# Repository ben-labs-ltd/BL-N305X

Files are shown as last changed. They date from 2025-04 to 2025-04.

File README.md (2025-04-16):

# BL-N305X
Meshtastic intended LoRa Node - Ben Labs Node 30.5dBm

## BL-N305A

Prototype board

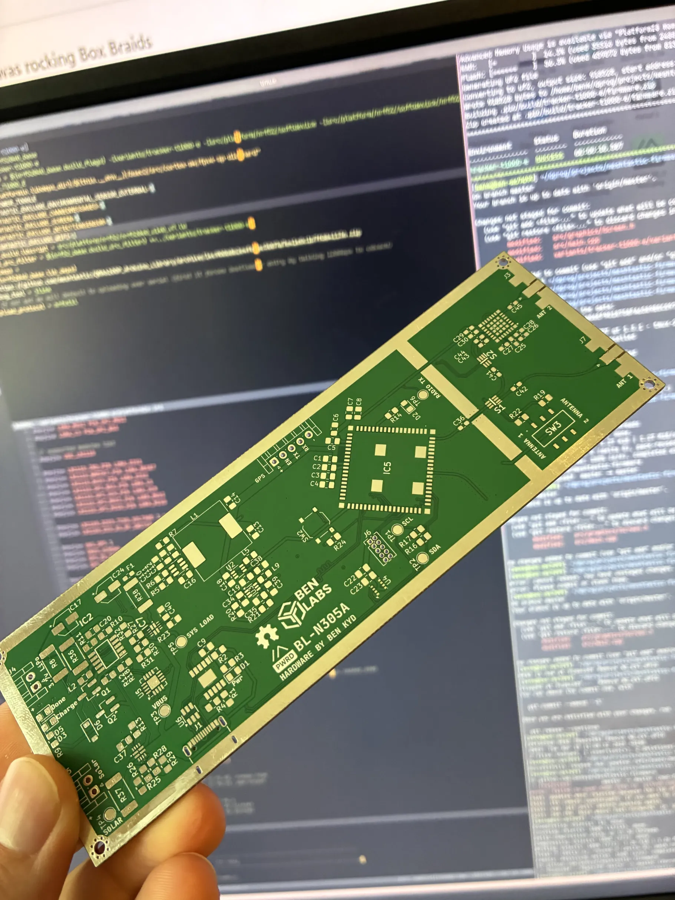
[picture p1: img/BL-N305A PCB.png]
Unpopulated PCB


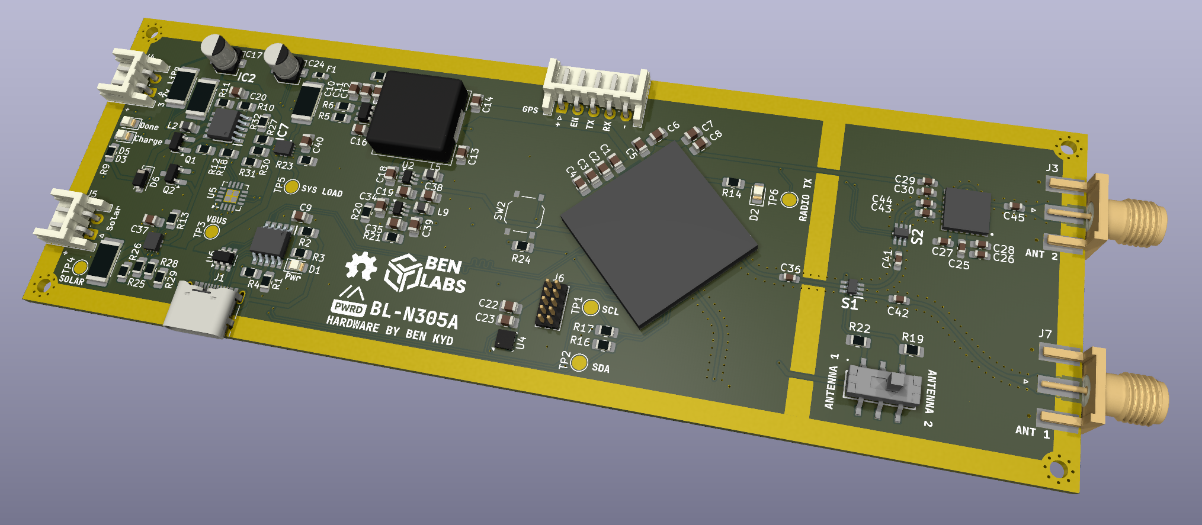
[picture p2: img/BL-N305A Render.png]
Render


## BL-N305B

Production ready board

OEM Price Point target £50
DIY Price Point target £30

### Considerations
- Use the SKY66122
- Move to using a bias-tee module for the amplification
- Compact compact compact

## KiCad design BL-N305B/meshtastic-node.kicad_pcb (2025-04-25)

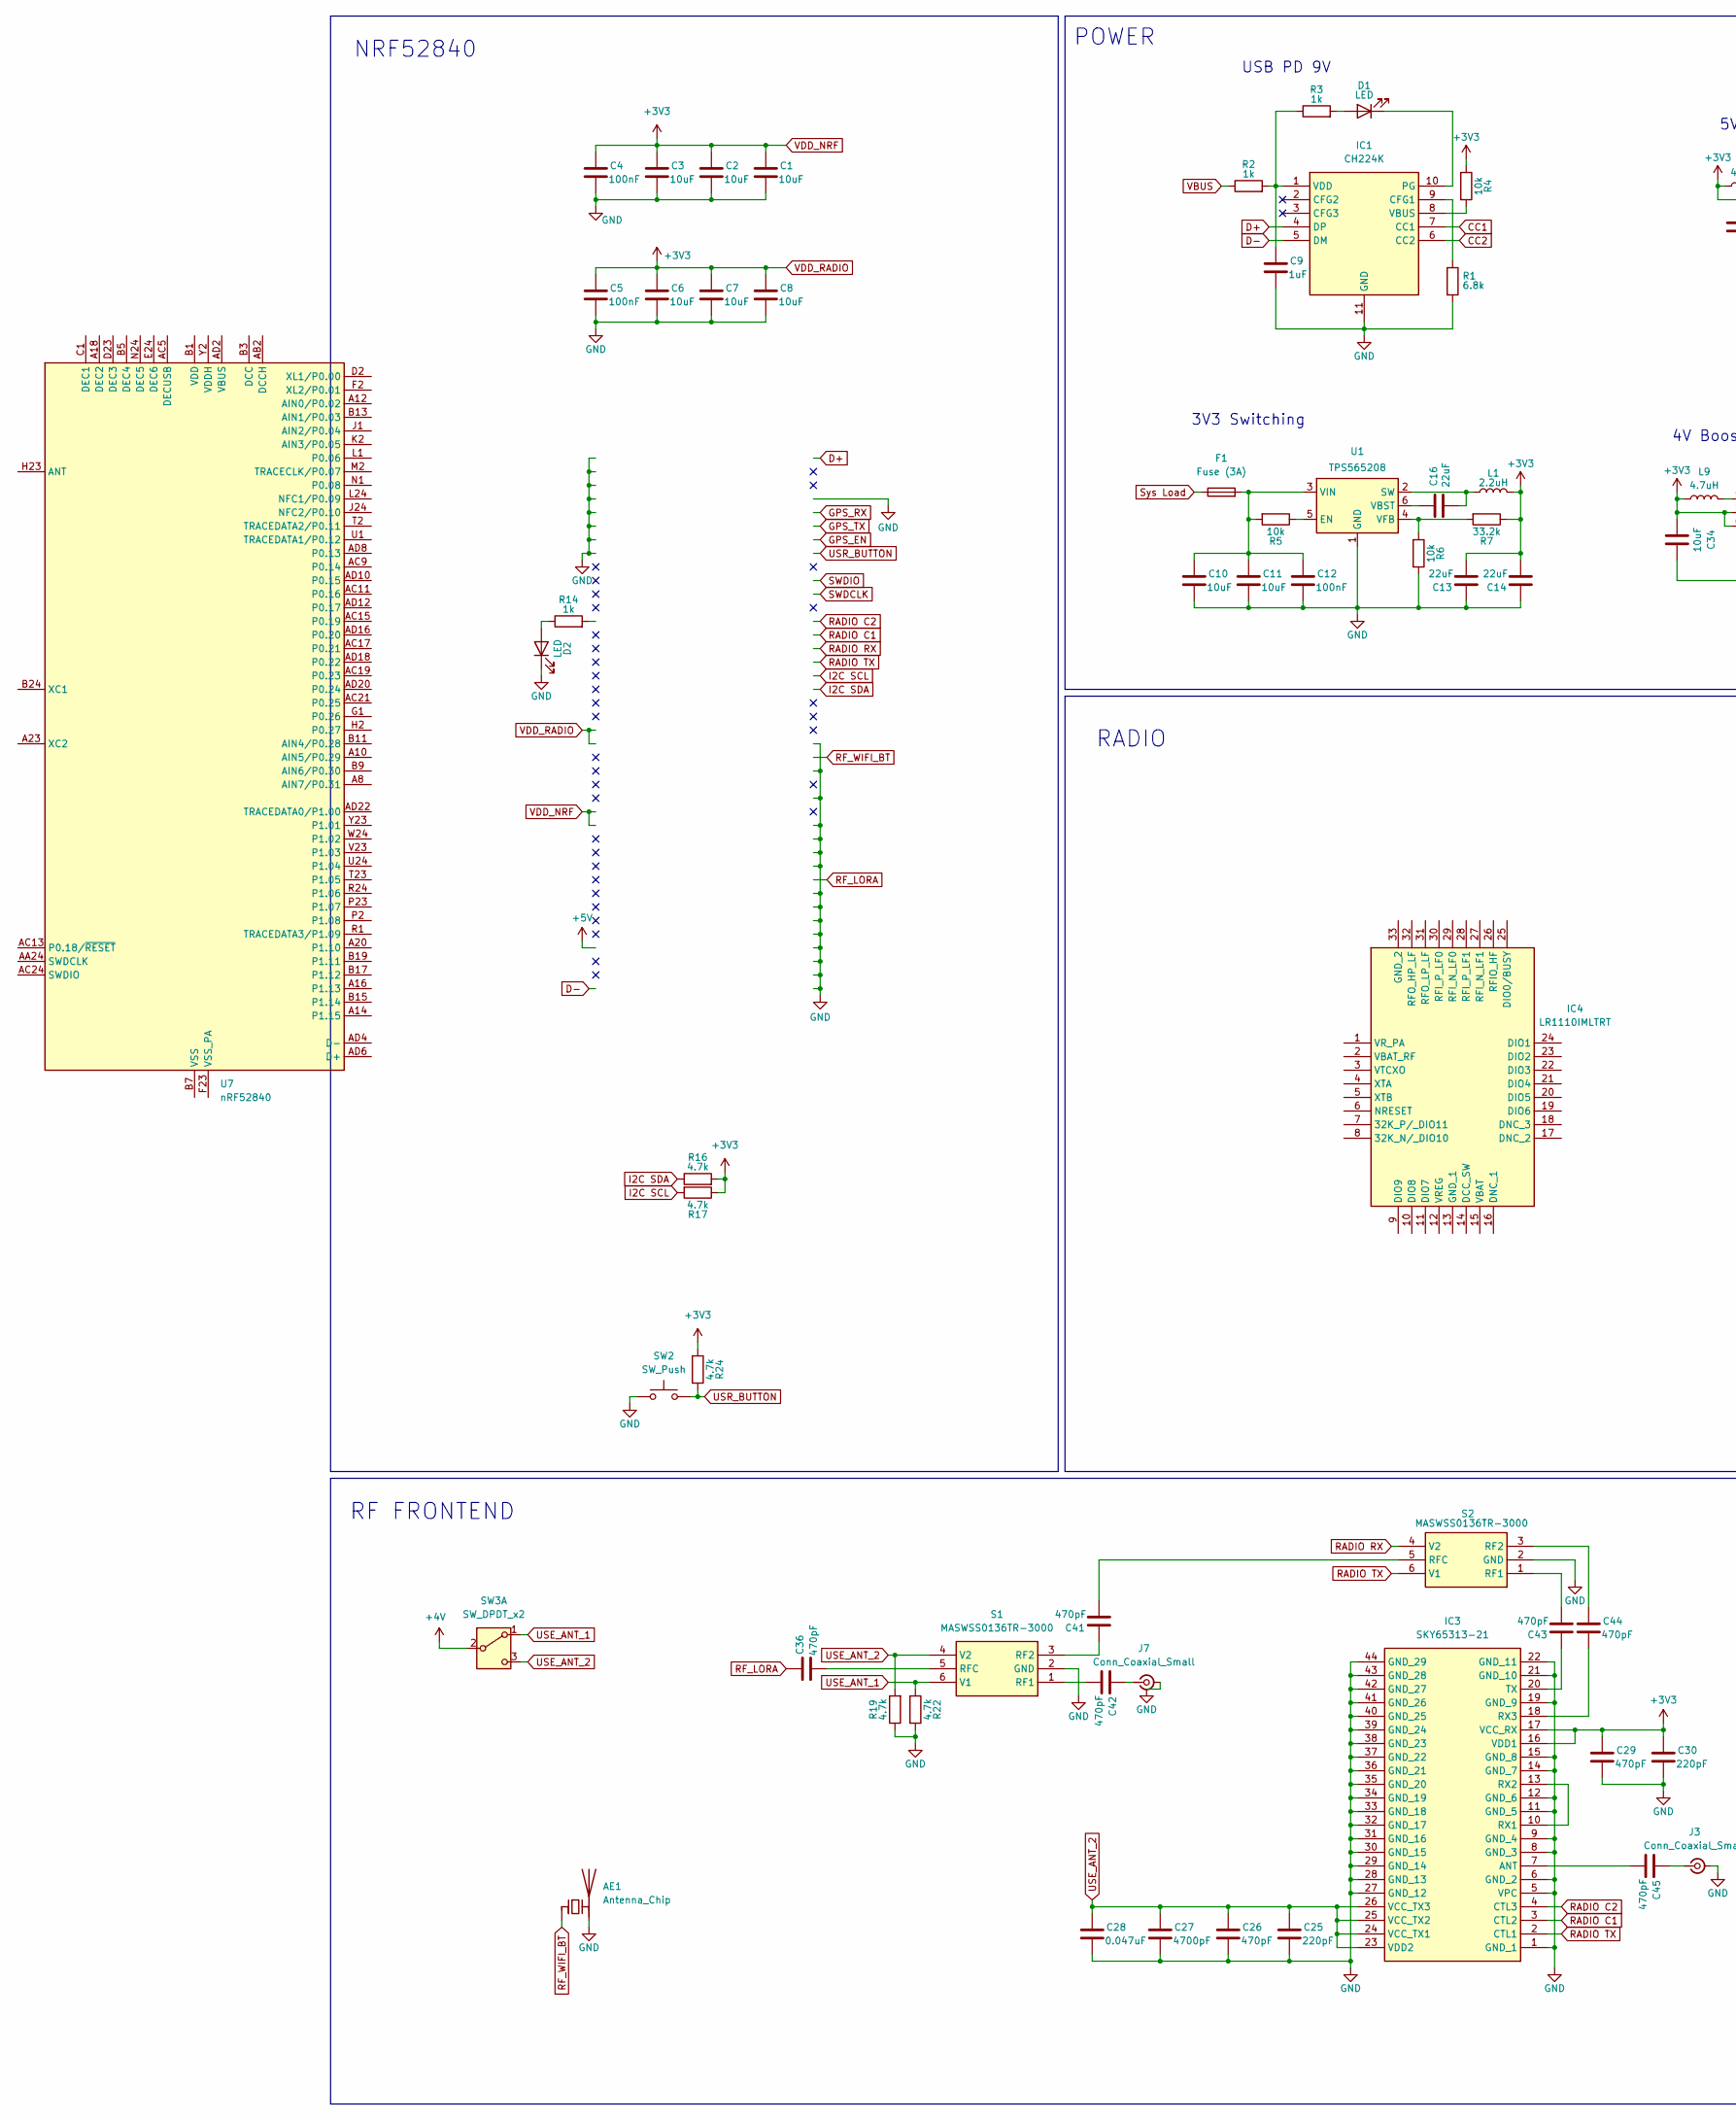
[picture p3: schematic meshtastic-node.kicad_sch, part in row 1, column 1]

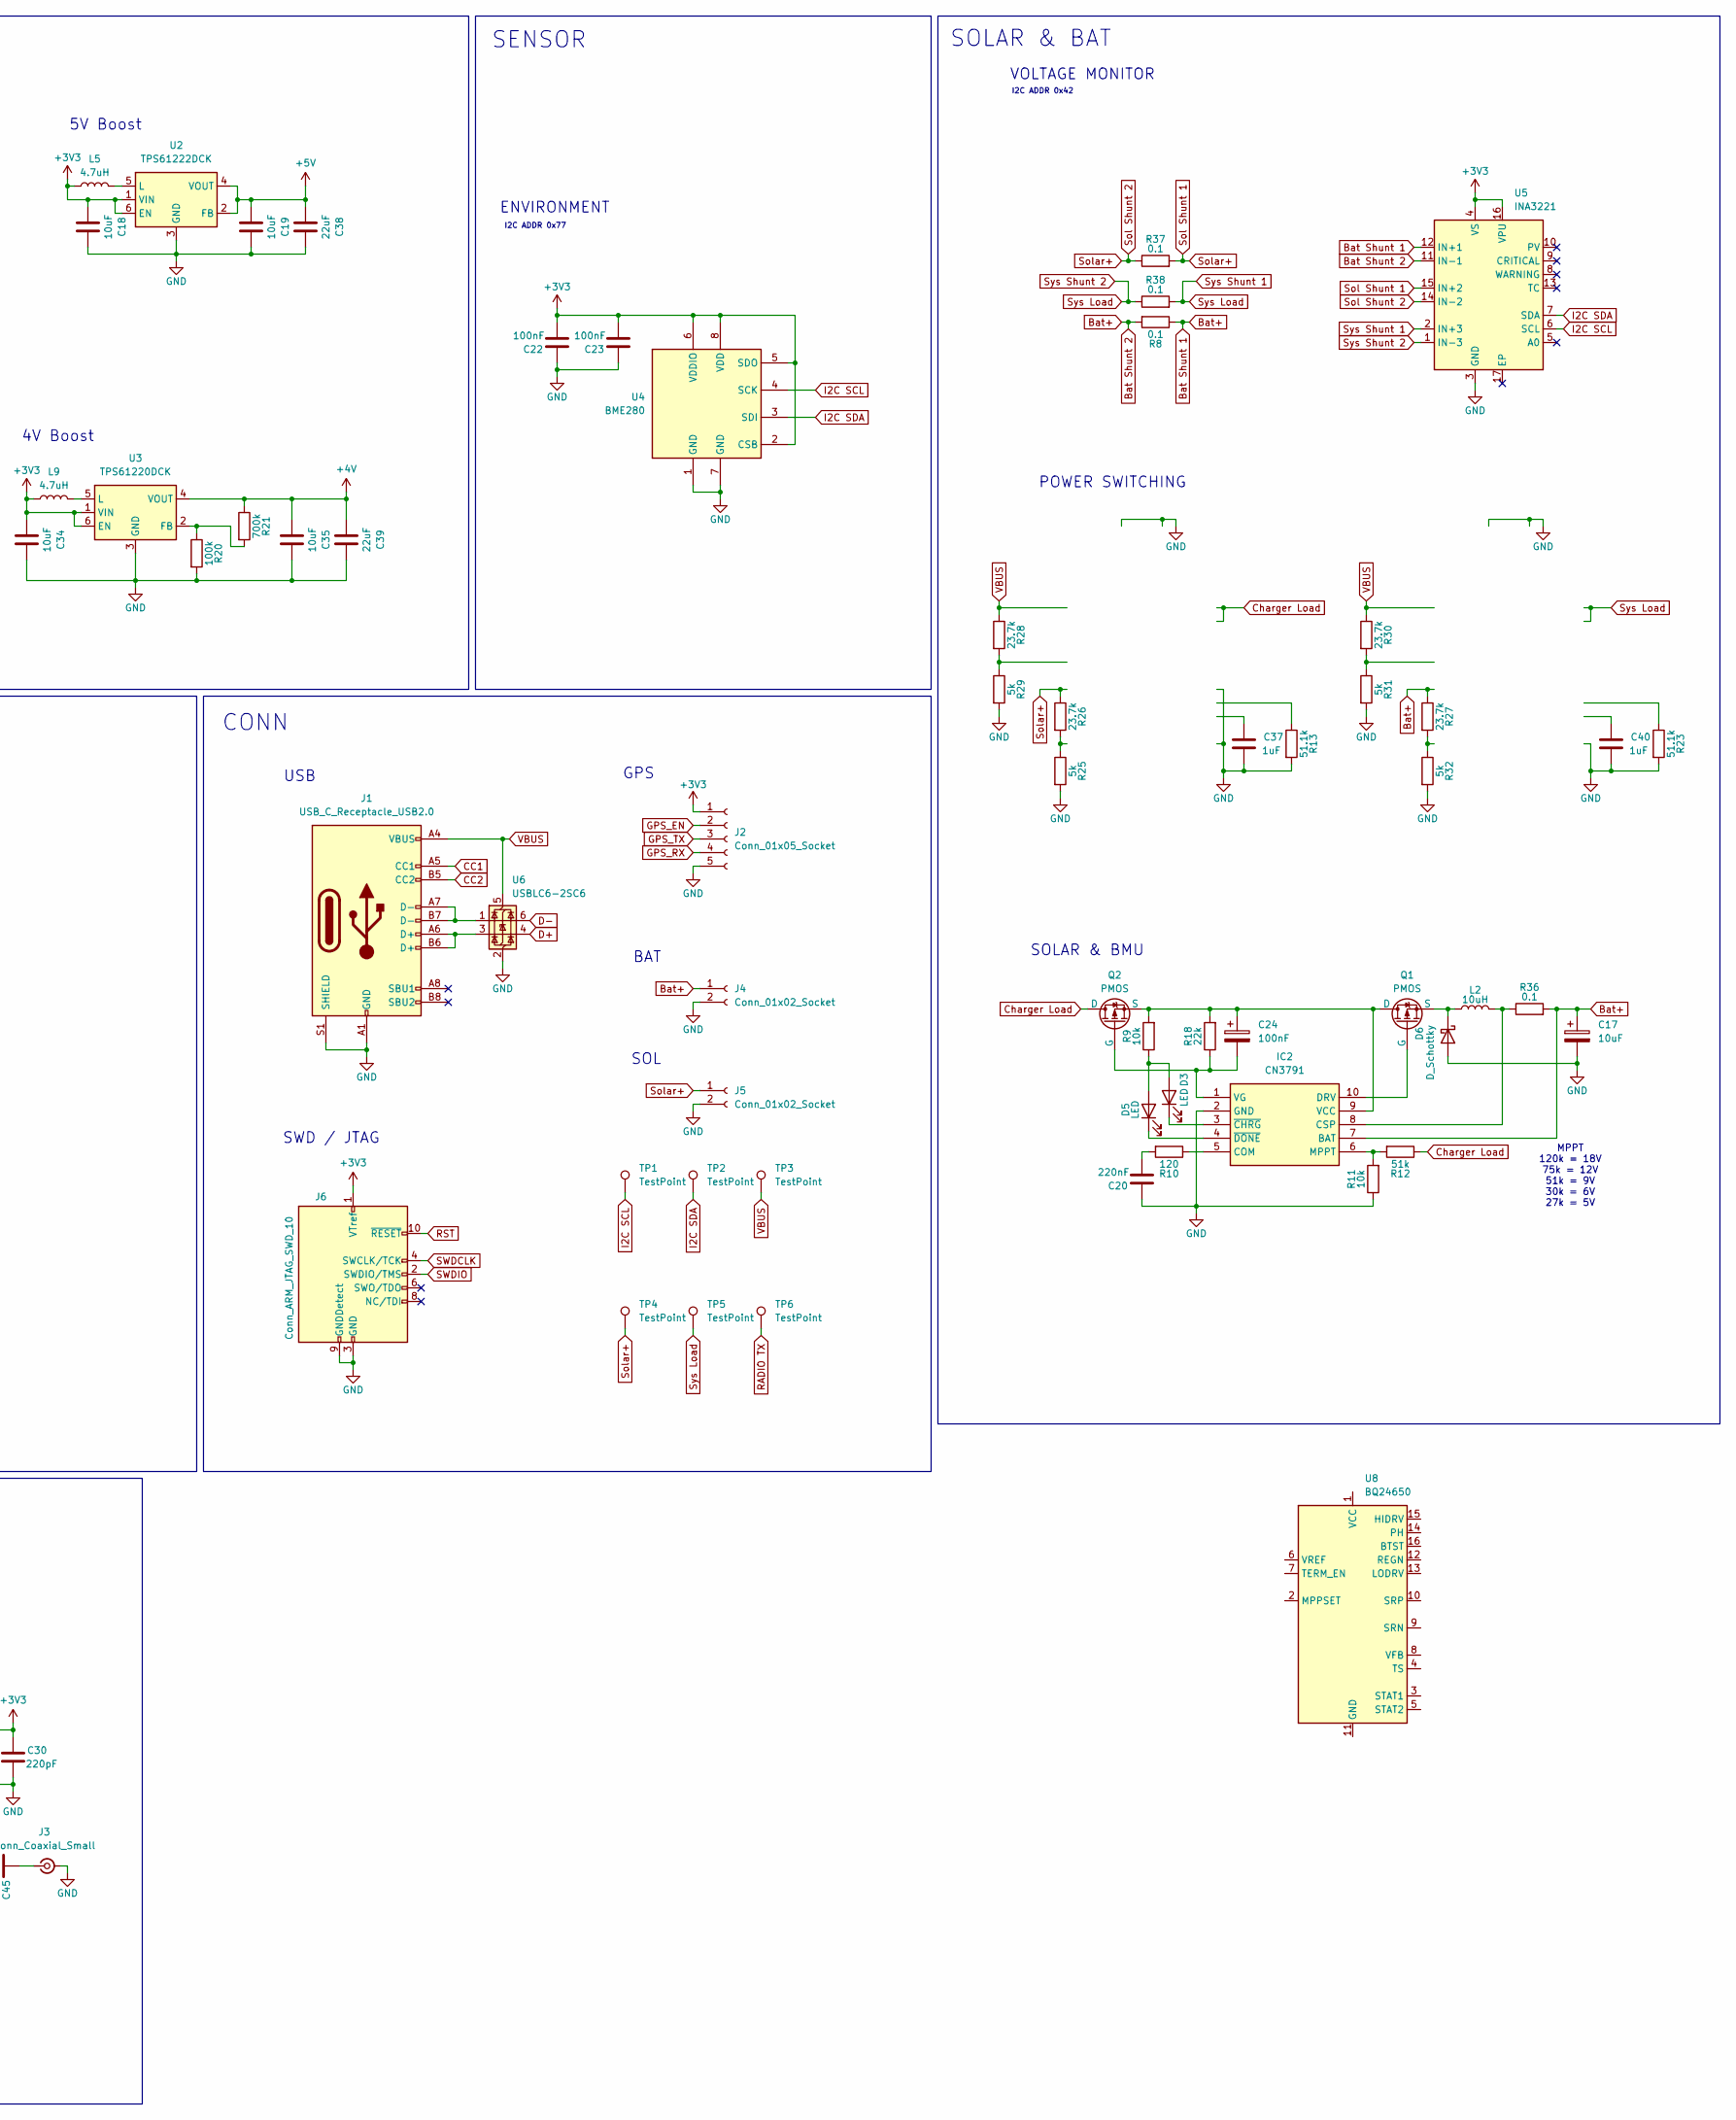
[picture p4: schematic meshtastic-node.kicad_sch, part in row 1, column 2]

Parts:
AE1: Antenna_Chip; Texas_SWRA117D_2.4GHz_Left
C1, C2, C3, C6, C7, C8, C10, C11, C18, C19, C34, C35: 10uF; C_0805_2012Metric_Pad1.18x1.45mm_HandSolder
C4, C5, C12, C22, C23: 100nF; C_0805_2012Metric_Pad1.18x1.45mm_HandSolder
C9, C37, C40: 1uF; C_0805_2012Metric_Pad1.18x1.45mm_HandSolder
C13, C14, C16, C38, C39: 22uF; C_0805_2012Metric_Pad1.18x1.45mm_HandSolder
C17: 10uF; CP_Elec_4x5.4
C20: 220nF; C_0805_2012Metric_Pad1.18x1.45mm_HandSolder
C24: 100nF; CP_Elec_4x5.4
C25, C30: 220pF; C_0603_1608Metric_Pad1.08x0.95mm_HandSolder
C26, C29, C36, C41, C42, C43, C44, C45: 470pF; C_0603_1608Metric_Pad1.08x0.95mm_HandSolder
C27: 4700pF; C_0603_1608Metric_Pad1.08x0.95mm_HandSolder
C28: 0.047uF; C_0603_1608Metric_Pad1.08x0.95mm_HandSolder
D1, D2, D3, D5: LED; LED_0805_2012Metric_Pad1.15x1.40mm_HandSolder
D6: D_Schottky; D_SOD-123
F1: Fuse (3A); Fuse_0603_1608Metric_Pad1.05x0.95mm_HandSolder
IC1: CH224K; SOP100P600X180-11N; Manufacturer_Part_Number CH224K; LCSC C970725
IC2: CN3791; SOP100P600X175-10N; Manufacturer_Part_Number CN3791; LCSC C154992
IC3: SKY65313-21; SKY6531321; Manufacturer_Part_Number SKY65313-21; Mouser Part Number 873-SKY65313-21
IC4: LR1110IMLTRT; QFN50P500X500X100-33N-D; Manufacturer_Part_Number LR1110IMLTRT; Mouser Part Number 947-LR1110IMLTRT
J1: USB_C_Receptacle_USB2.0; USB_C_Receptacle_G-Switch_GT-USB-7010ASV
J2: Conn_01x05_Socket; JST_EH_S5B-EH_1x05_P2.50mm_Horizontal
J3, J7: Conn_Coaxial_Small; SMA_Molex_73251-1153_EdgeMount_Horizontal
J4, J5: Conn_01x02_Socket; JST_EH_S2B-EH_1x02_P2.50mm_Horizontal
J6: Conn_ARM_JTAG_SWD_10; PinHeader_2x05_P1.27mm_Vertical
L1: 2.2uH; L_SXN_SMDRI124; LCSC C2929497
L2: 10uH; L_0805_2012Metric_Pad1.15x1.40mm_HandSolder
L5, L9: 4.7uH; L_0805_2012Metric_Pad1.15x1.40mm_HandSolder
Q1, Q2: PMOS; SOT-23_Handsoldering
R1: 6.8k; R_0805_2012Metric_Pad1.20x1.40mm_HandSolder
R2, R3, R14: 1k; R_0805_2012Metric_Pad1.20x1.40mm_HandSolder
R4, R5, R6, R9, R11: 10k; R_0805_2012Metric_Pad1.20x1.40mm_HandSolder
R7: 33.2k; R_0805_2012Metric_Pad1.20x1.40mm_HandSolder
R8, R36, R37, R38: 0.1; R_2512_6332Metric_Pad1.40x3.35mm_HandSolder
R10: 120; R_0805_2012Metric_Pad1.20x1.40mm_HandSolder
R12: 51k; R_0805_2012Metric_Pad1.20x1.40mm_HandSolder
R13, R23: 51.1k; R_0805_2012Metric_Pad1.20x1.40mm_HandSolder
R16, R17, R19, R22, R24: 4.7k; R_0805_2012Metric_Pad1.20x1.40mm_HandSolder
R18: 22k; R_0805_2012Metric_Pad1.20x1.40mm_HandSolder
R20: 100k; R_0805_2012Metric_Pad1.20x1.40mm_HandSolder
R21: 700k; R_0805_2012Metric_Pad1.20x1.40mm_HandSolder
R25, R29, R31, R32: 5k; R_0805_2012Metric_Pad1.20x1.40mm_HandSolder
R26, R27, R28, R30: 23.7k; R_0805_2012Metric_Pad1.20x1.40mm_HandSolder
S1, S2: MASWSS0136TR-3000; SOT65P210X110-6N; Manufacturer_Part_Number MASWSS0136TR-3000; Mouser Part Number 937-MASWSS0136-T
SW2: SW_Push; SW_Push_1P1T_XKB_TS-1187A; LCSC C42420254
SW3: SW_DPDT_x2; SS3235SL3; LCSC C381098
TP1, TP2, TP3, TP4, TP5, TP6: TestPoint; TestPoint_Pad_D2.0mm
U1: TPS565208; SOT-23-6; LCSC C2650336
U2: TPS61222DCK; Texas_R-PDSO-G6; LCSC C116461
U3: TPS61220DCK; Texas_R-PDSO-G6; LCSC C116461
U4: BME280; Bosch_LGA-8_2.5x2.5mm_P0.65mm_ClockwisePinNumbering; LCSC C92489
U5: INA3221; Texas_RGV0016A_VQFN-16-1EP_4x4mm_P0.65mm_EP2.1x2.1mm; LCSC C181255
U6: USBLC6-2SC6; SOT-23-6
U7: nRF52840; Nordic_AQFN-73-1EP_7x7mm_P0.5mm
U8: BQ24650; Texas_RVA_VQFN-16-1EP_3.5x3.5mm_P0.5mm_EP2.14x2.14mm_Therma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

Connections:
+4V: C35.1, C39.1, R21.1, SW3.2 (B), U3.4 (VOUT)
+5V: C19.1, C38.1, U2.2 (FB), U2.4 (VOUT)
Bat Shunt 1: C17.1, IC2.7 (BAT), J4.1, R8.1, R8.2, R27.1, R36.2, U5.11 (IN-1), U5.12 (IN+1)
CC1: IC1.7 (CC1), J1.A5 (CC1)
CC2: IC1.6 (CC2), J1.B5 (CC2)
Charger Load: Q2.1 (D), R12.1
D+: IC1.4 (DP), U6.4 (I/O2)
D-: IC1.5 (DM), U6.6 (I/O1)
GND: AE1.2 (PCB_Trace), C1.2, C2.2, C3.2, C4.2, C5.2, C6.2, C7.2, C8.2, C9.2, C10.2, C11.2, C12.2, C13.1, C14.1, C17.2, C18.2, C19.2, C20.1, C22.1, C23.1, C25.2, C26.2, C27.2, C28.2, C29.2, C30.2, C34.2, C35.2, C37.2, C38.2, C39.2, C40.2, D2.1 (K), D6.2 (A), IC1.11 (GND), IC2.2 (GND), IC3.1 (GND_1), IC3.5 (VPC), IC3.6 (GND_2), IC3.8 (GND_3), IC3.9 (GND_4), IC3.11 (GND_5), IC3.12 (GND_6), IC3.14 (GND_7), IC3.15 (GND_8), IC3.19 (GND_9), IC3.21 (GND_10), IC3.22 (GND_11), IC3.27 (GND_12), IC3.28 (GND_13), IC3.29 (GND_14), IC3.30 (GND_15), IC3.31 (GND_16), IC3.32 (GND_17), IC3.33 (GND_18), IC3.34 (GND_19), IC3.35 (GND_20), IC3.36 (GND_21), IC3.37 (GND_22), IC3.38 (GND_23), IC3.39 (GND_24), IC3.40 (GND_25), IC3.41 (GND_26), IC3.42 (GND_27), IC3.43 (GND_28), IC3.44 (GND_29), J1.A1 (GND), J1.A12 (GND), J1.B1 (GND), J1.B12 (GND), J1.S1 (SHIELD), J2.5, J3.2 (Ext), J4.2, J5.2, J6.3 (GND), J6.5 (GND), J6.9 (GNDDetect), J7.2 (Ext), R1.2, R6.2, R11.1, R13.2, R19.1, R20.2, R22.2, R23.2, R25.2, R29.2, R31.2, R32.2, S1.2 (GND), S2.2 (GND), SW2.1, U1.1 (GND), U2.3 (GND), U3.3 (GND), U4.1 (GND), U4.7 (GND), U5.3 (GND), U6.2 (GND)
GPS_EN: J2.2
GPS_RX: J2.4
GPS_TX: J2.3
I2C SCL: R17.2, TP1.1, U4.4 (SCK), U5.6 (SCL)
I2C SDA: R16.1, TP2.1, U4.3 (SDI), U5.7 (SDA)
unnamed: C20.2, R10.2
unnamed: D1.2 (A), R3.2
unnamed: D1.1 (K), IC1.10 (PG)
unnamed: D2.2 (A), R14.1
unnamed: D3.2 (A), D5.2 (A), R9.1
unnamed: D3.1 (K), IC2.3 (~CHRG)
unnamed: D5.1 (K), IC2.4 (~DONE)
unnamed: D6.1 (K), L2.1, Q1.3 (S)
unnamed: IC1.9 (CFG1), R1.1
unnamed: IC1.8 (VBUS), R4.2
unnamed: C9.1, IC1.1 (VDD), R2.2, R3.1
unnamed: IC2.5 (COM), R10.1
unnamed: IC2.8 (CSP), L2.2, R36.1
unnamed: IC2.10 (DRV), Q1.2 (G)
unnamed: IC2.6 (MPPT), R11.2, R12.2
unnamed: C24.1, IC2.9 (VCC), Q1.1 (D), Q2.3 (S), R9.2, R18.2
unnamed: C24.2, IC2.1 (VG), Q2.2 (G), R18.1
unnamed: C45.2, IC3.7 (ANT)
unnamed: IC3.10 (RX1), IC3.13 (RX2)
unnamed: C44.2, IC3.18 (RX3)
unnamed: C43.1, IC3.20 (TX)
unnamed: J1.A6 (D+), J1.B6 (D+), U6.3 (I/O2)
unnamed: J1.A7 (D-), J1.B7 (D-), U6.1 (I/O1)
unnamed: C45.1, J3.1 (In)
unnamed: C42.1, J7.1 (In)
unnamed: R25.1, R26.2
unnamed: R27.2, R32.1
unnamed: R28.2, R29.1
unnamed: R30.2, R31.1
unnamed: C42.2, S1.1 (RF1)
unnamed: C41.1, S1.3 (RF2)
unnamed: C36.2, S1.5 (RFC)
unnamed: C43.2, S2.1 (RF1)
unnamed: C44.1, S2.3 (RF2)
unnamed: C41.2, S2.5 (RFC)
unnamed: R5.1, U1.5 (EN)
unnamed: C16.2, L1.1, U1.2 (SW)
unnamed: C16.1, U1.6 (VBST)
unnamed: R6.1, R7.2, U1.4 (VFB)
unnamed: C10.1, C11.1, C12.1, F1.2, R5.2, U1.3 (VIN)
unnamed: L5.2, U2.5 (L)
unnamed: R20.1, R21.2, U3.2 (FB)
unnamed: L9.2, U3.5 (L)
unnamed: U7.A22 (VDD), U7.AD14 (VDD), U7.AD23 (VDD), U7.B1 (VDD), U7.W1 (VDD)
unnamed: U7.B7 (VSS), U7.EP (VSS)
unnamed: U8.11 (GND), U8.17 (GND)
RADIO C1: IC3.3 (CTL2)
RADIO C2: IC3.4 (CTL3)
RADIO RX: S2.4 (V2)
RADIO TX: IC3.2 (CTL1), S2.6 (V1), TP6.1
RF_LORA: C36.1
RF_WIFI_BT: AE1.1 (FEED)
RST: J6.10 (~RESET)
SWDCLK: J6.4 (SWCLK/TCK)
SWDIO: J6.2 (SWDIO/TMS)
Sol Shunt 1: J5.1, R26.1, R37.1, R37.2, TP4.1, U5.14 (IN-2), U5.15 (IN+2)
Sys Load: F1.1, R38.1, R38.2, TP5.1, U5.1 (IN-3), U5.2 (IN+3)
USE_ANT_1: R22.1, S1.6 (V1), SW3.1 (A)
USE_ANT_2: C25.1, C26.1, C27.1, C28.1, IC3.23 (VDD2), IC3.24 (VCC_TX1), IC3.25 (VCC_TX2), IC3.26 (VCC_TX3), R19.2, S1.4 (V2), SW3.3 (C)
USR_BUTTON: R24.2, SW2.2
VBUS: J1.A4 (VBUS), J1.A9 (VBUS), J1.B4 (VBUS), J1.B9 (VBUS), R2.1, R28.1, R30.1, TP3.1, U6.5 (VBUS)
VDD_NRF: C1.1, C2.1, C3.1, C4.1, C5.1, C6.1, C7.1, C8.1, C13.2, C14.2, C18.1, C22.2, C23.2, C29.1, C30.1, C34.1, IC3.16 (VDD1), IC3.17 (VCC_RX), J2.1, J6.1 (VTref), L1.2, L5.1, L9.1, R4.1, R7.1, R16.2, R17.1, R24.1, U2.1 (VIN), U2.6 (EN), U3.1 (VIN), U3.6 (EN), U4.2 (CSB), U4.5 (SDO), U4.6 (VDDIO), U4.8 (VDD), U5.4 (VS), U5.16 (VPU)

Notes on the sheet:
I2C ADDR 0x77
3V3 Switching
GPS
MPPT 120k = 18V 75k = 12V 51k = 9V 30k = 6V 27k = 5V
ENVIRONMENT
BAT
SENSOR
RADIO
VOLTAGE MONITOR
5V Boost
CONN
SOL
4V Boost
SOLAR & BAT
SWD / JTAG
I2C ADDR 0x42
NRF52840
USB PD 9V
SOLAR & BMU
POWER
USB
RF FRONTEND
POWER SWITCHING

Board: 2 copper layers, 115 parts (0 on the bottom side), 64 nets, no tracks yet.
